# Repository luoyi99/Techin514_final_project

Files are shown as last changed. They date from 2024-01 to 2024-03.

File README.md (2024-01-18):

# Techin514_final_project
## Part 1
### Jumping Jacks Counter
 A basic fitness tracker that monitors and displays key metrics like the number of jumps, rate (jumps per minute), heart rate and calories burned. The project integrates an accelerometer for motion sensing, a pulse sensor for heart rate monitoring, a display mechanism using screen and stepper motor-driven gauge needle, and a button for reset.
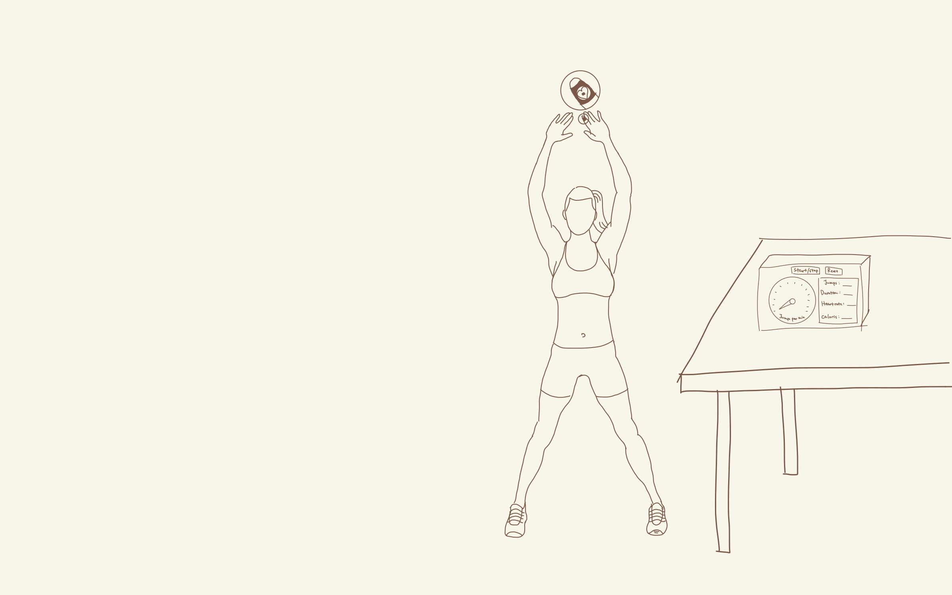
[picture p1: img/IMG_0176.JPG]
Image of how the device work


## Part 2 - Sensor Device
The sensor device will include a MPU6050 motion sensor, a pulse sensor, a ESP32S3 processor and a battery. The components will be sewed on a glove so users can wear it when doing jumping jacks without worrying it to fall down.
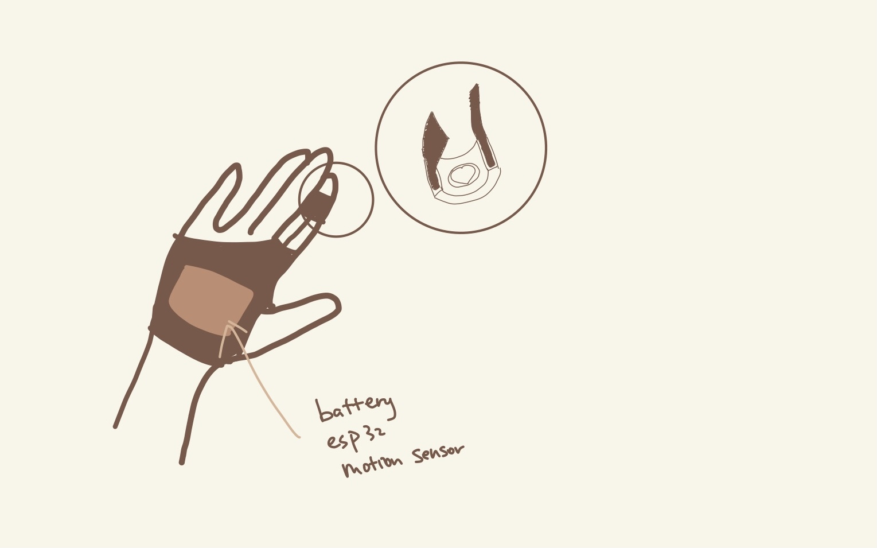
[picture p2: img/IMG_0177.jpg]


## Part 3 - Display Device
The display device will include a ESP32S3 processor, a battery, a OLED screen, a button, a LED, a stepper motor driver breakout board (Adafruit TB6612 1.2A DC/Stepper Motor Driver Breakout Board) and a stepper-motor-driven gauge needle (x27.168). 
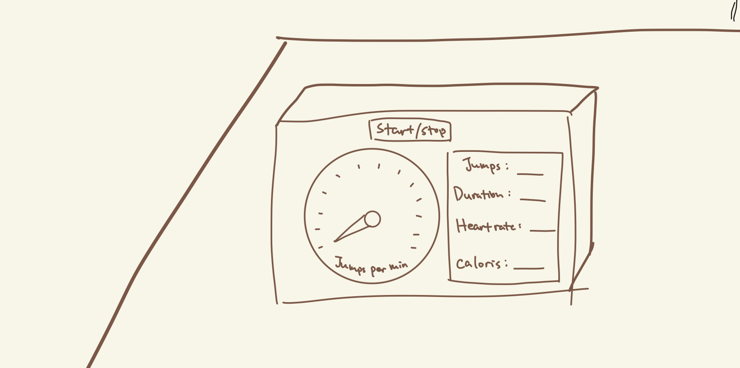
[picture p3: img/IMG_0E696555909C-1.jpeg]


## Part 4
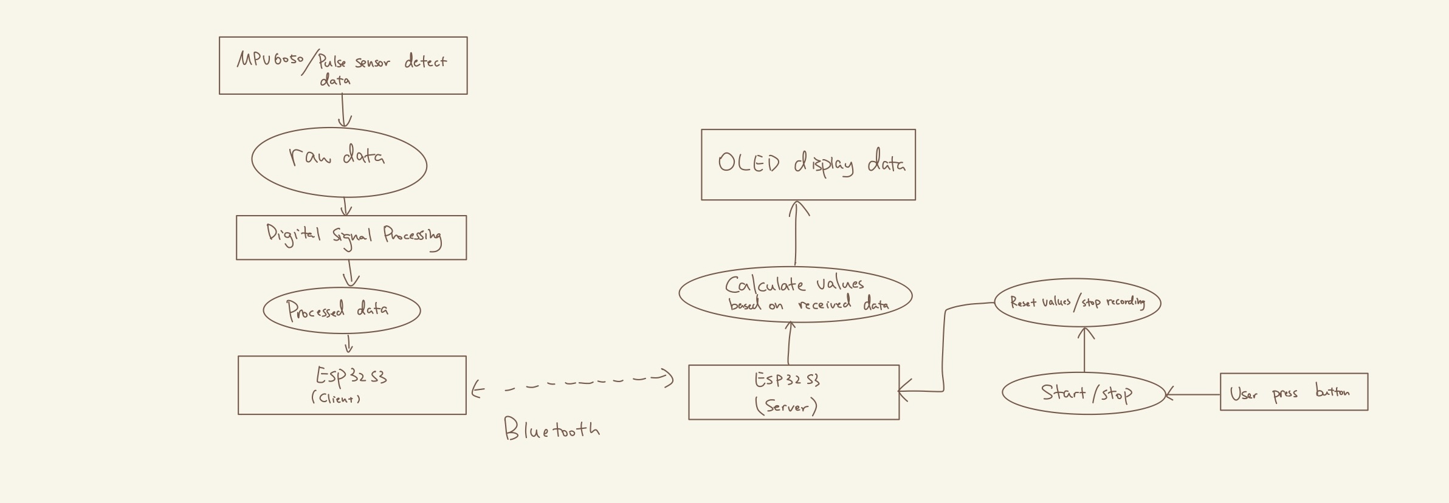
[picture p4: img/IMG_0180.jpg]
Image of how the devices communicate

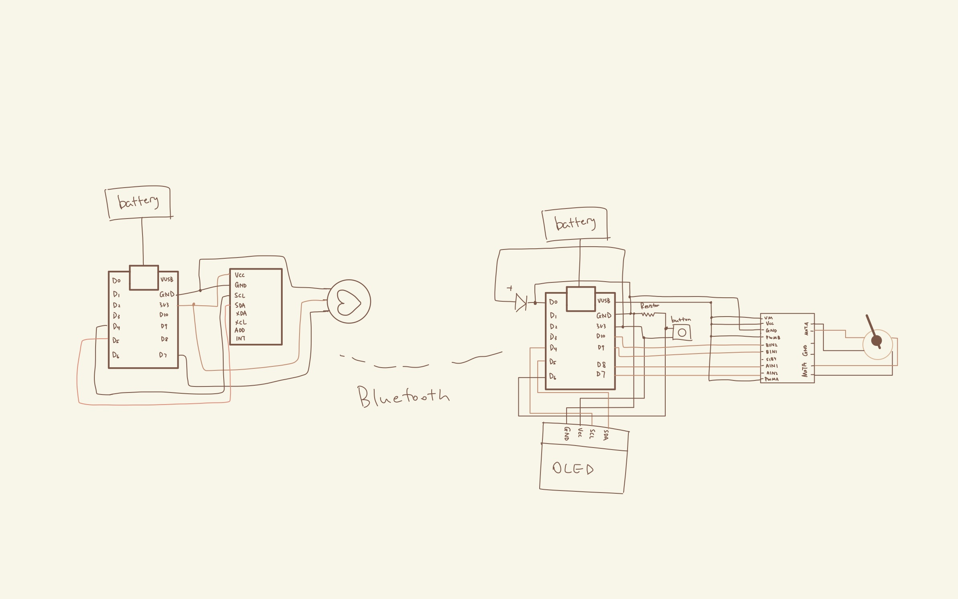
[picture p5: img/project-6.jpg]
Image of how the devices connected


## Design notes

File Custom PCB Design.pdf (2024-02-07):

## Jumping Jacks Counter - Sensor Device

1) A list of all the electronic components that will be soldered to your PCB Resistors
R1 - 1k Ohms
R2 - 4.7k Ohms
R3 - 4.7k Ohms
Capacitors
C4 - 200 pf
C5 - 0.1 uf
C6 - 0.1 uf
C7 - 0.1 uf
Button
Battery holder
LED
Pulse Sensor
SEN - 11574
Motion Sensor
MPU-6050
2) A screenshot of your circuit in the Schematic Editor window of KiCad

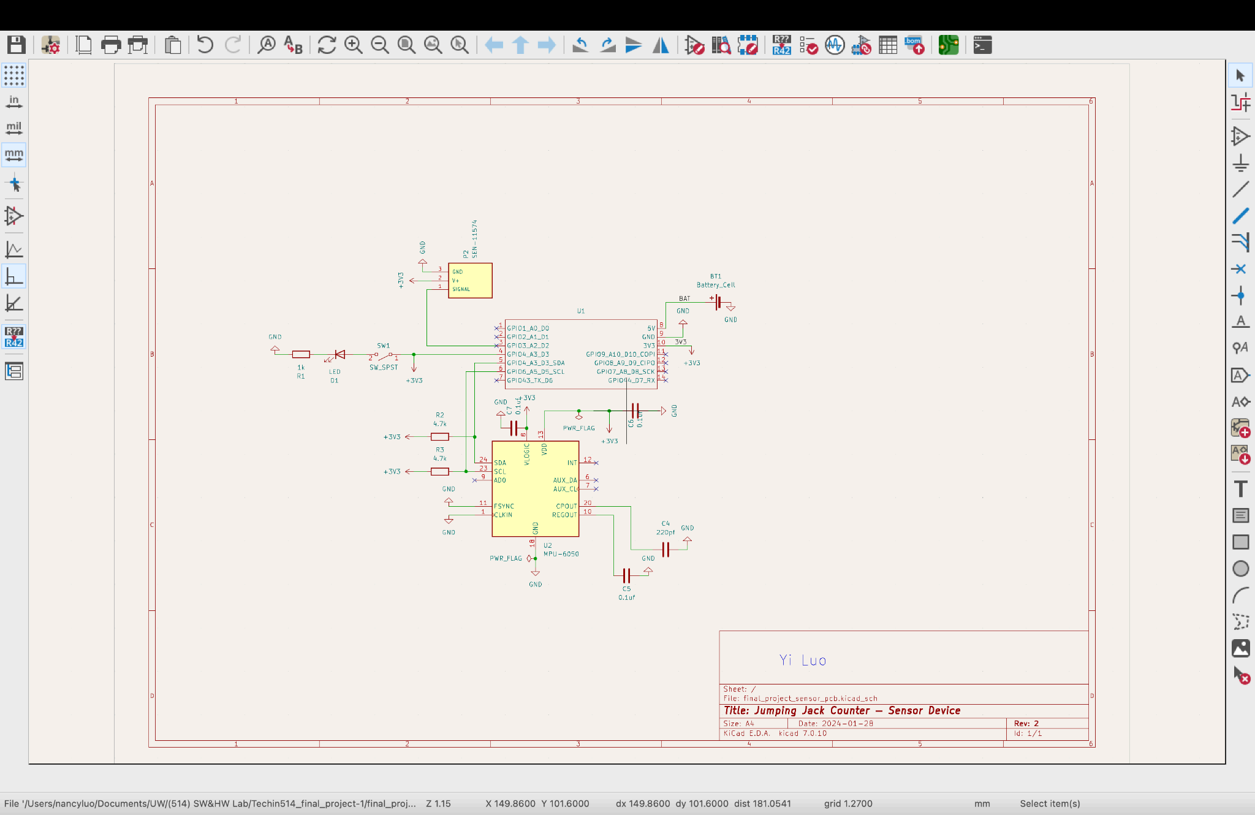
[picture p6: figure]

3) A screenshot of your circuit board in the PCB Editor window of KiCad

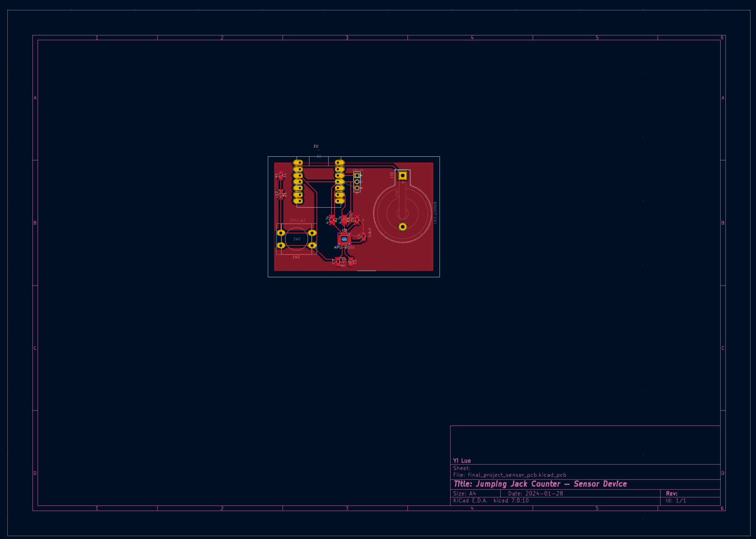
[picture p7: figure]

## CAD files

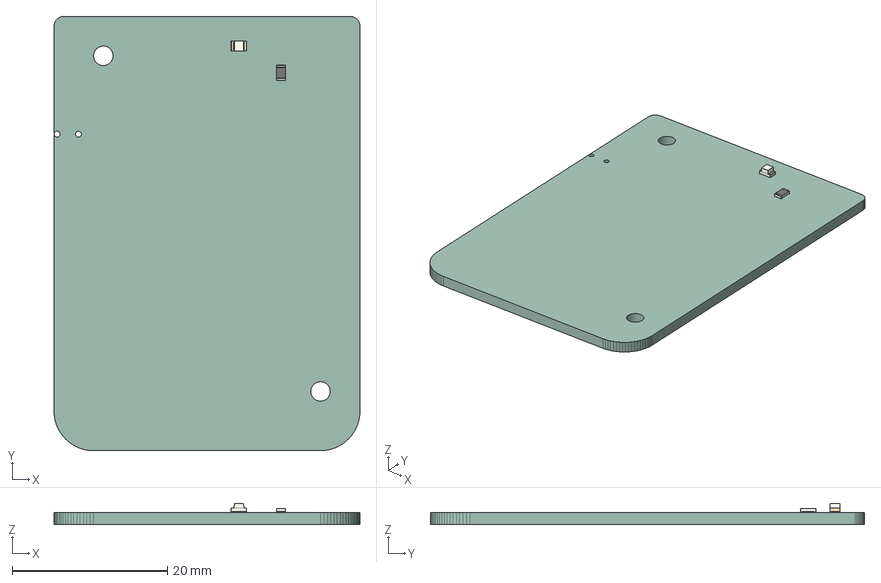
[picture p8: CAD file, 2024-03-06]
CAD/lightboard.step
39.4 x 55.9 x 2.75 mm
lightboard PCB

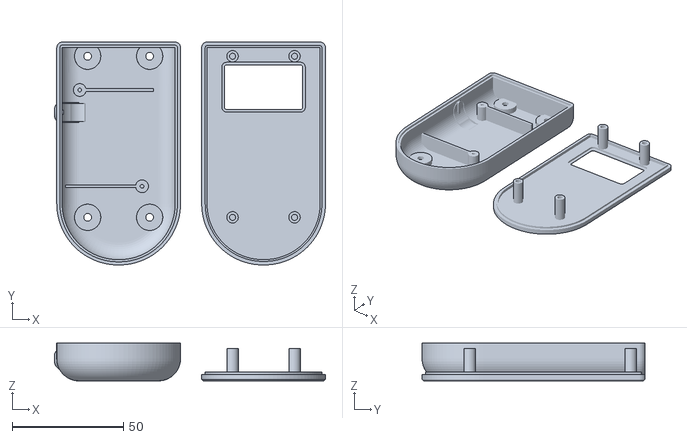
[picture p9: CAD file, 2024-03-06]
CAD/Enclosure_Example_20240207 v1.stl
121.6 x 100.0 x 17.0

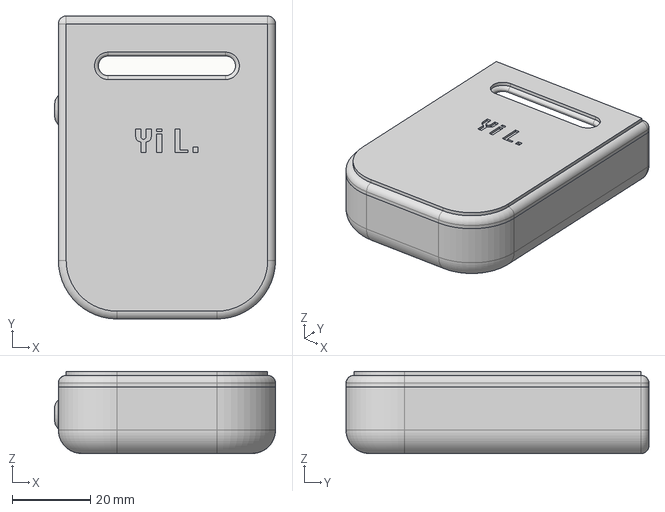
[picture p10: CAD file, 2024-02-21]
PCB/sensor_pcb_breakout_board/EnclosureDesignLabv3 v2.step
56.6 x 77.5 x 21.0 mm

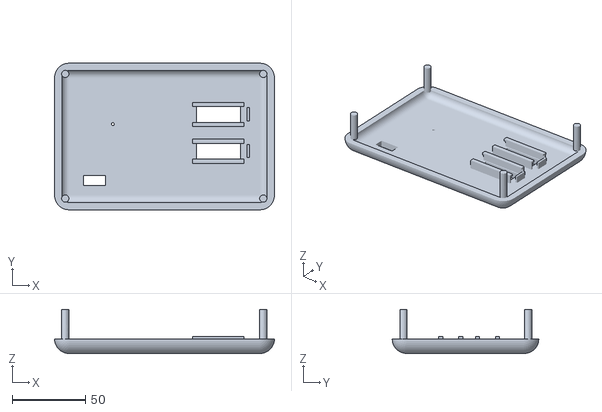
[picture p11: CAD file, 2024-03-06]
CAD/Display v2.stl
150.0 x 100.0 x 30.0

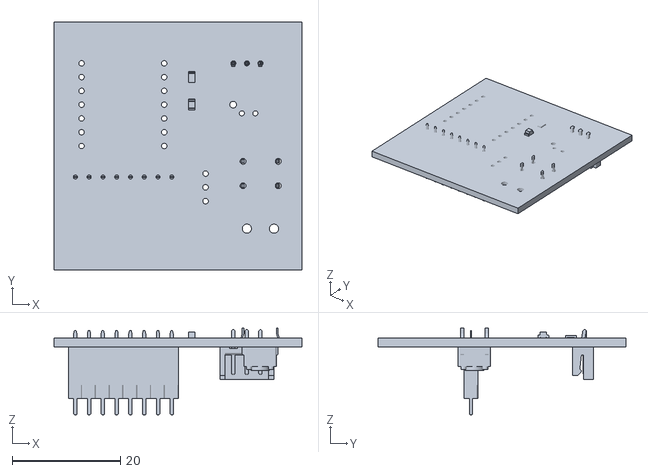
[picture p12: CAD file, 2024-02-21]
PCB/sensor_pcb_breakout_board/final_project_sensor_pcb v1.stl
45.7 x 45.7 x 16.0

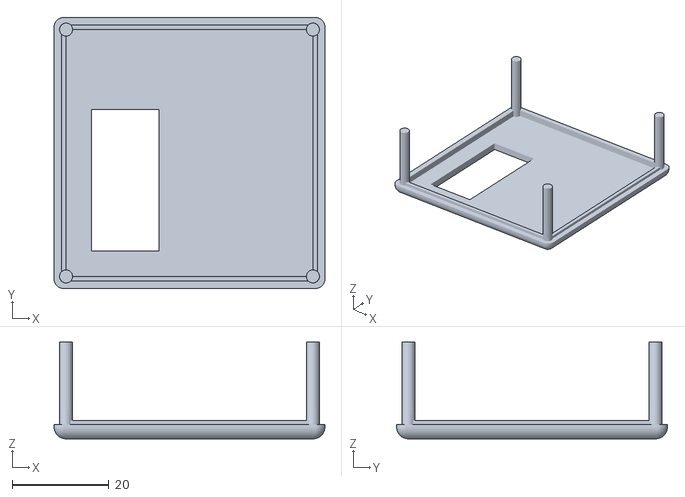
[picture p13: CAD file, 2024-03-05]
CAD/Sensor v3.stl
56.0 x 56.0 x 20.0

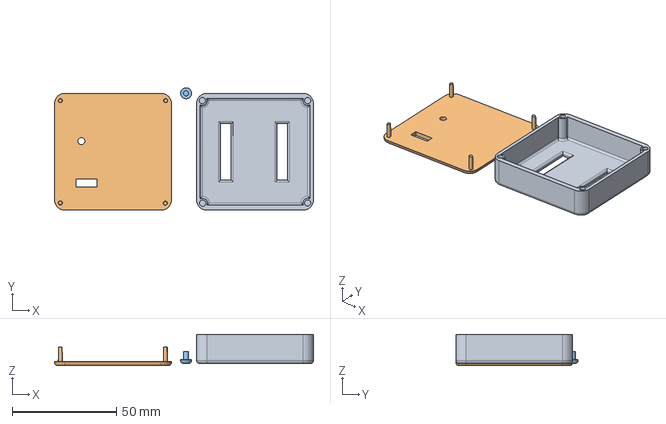
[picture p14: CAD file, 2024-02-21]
PCB/sensor_pcb_breakout_board/Final_Sensor v6.step
124.0 x 58.6 x 15.0 mm

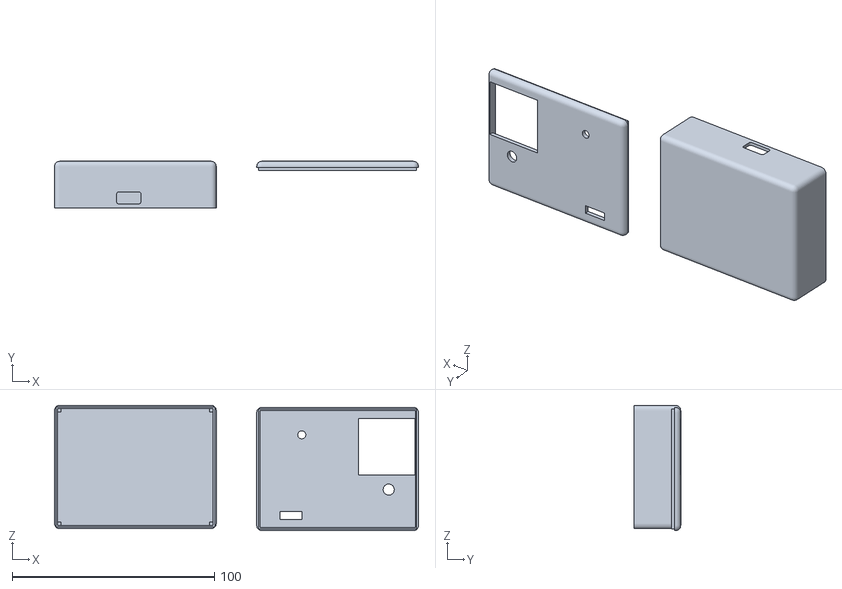
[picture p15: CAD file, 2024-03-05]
CAD/Display_Final v6.stl
180.0 x 23.0 x 62.0

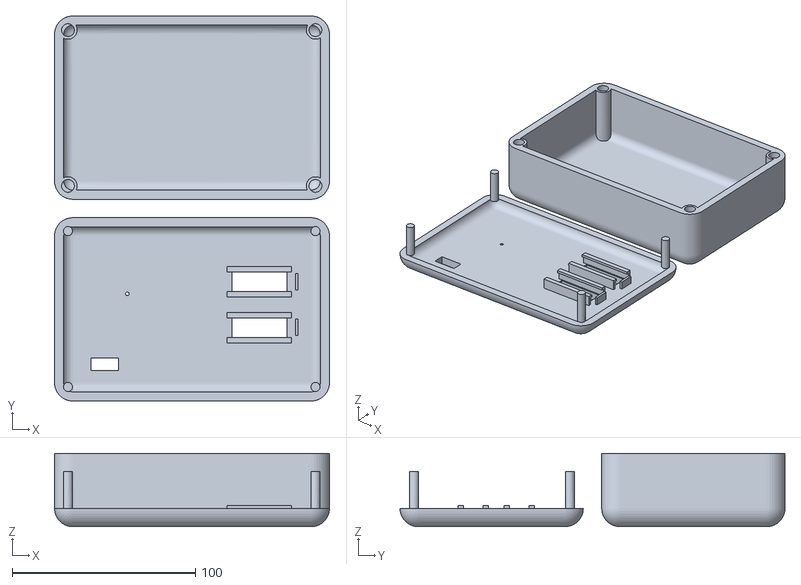
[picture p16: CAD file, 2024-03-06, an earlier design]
CAD/Display v1.stl
150.0 x 210.0 x 40.0

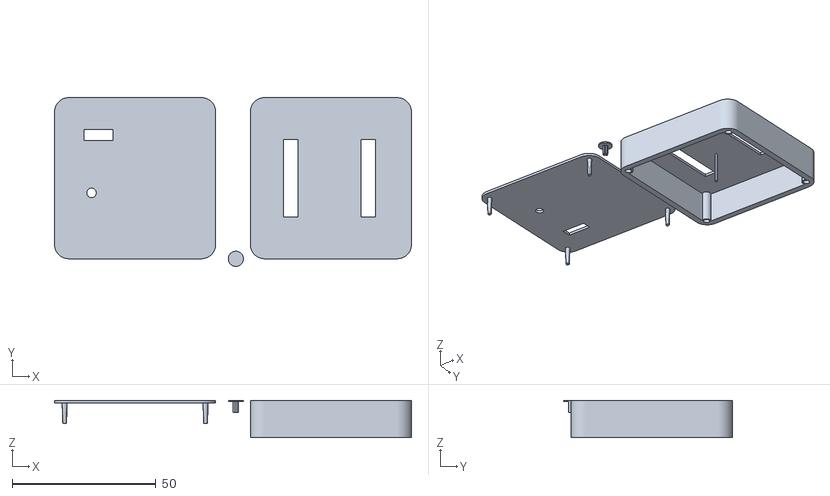
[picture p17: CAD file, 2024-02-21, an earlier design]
PCB/sensor_pcb_breakout_board/Final_Sensor v2.stl
124.0 x 58.6 x 13.0

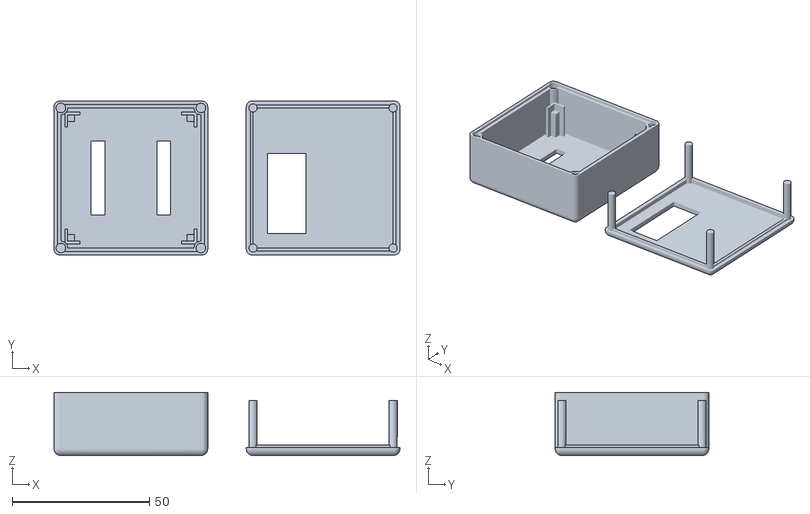
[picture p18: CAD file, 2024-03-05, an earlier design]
CAD/Sensor v2.stl
126.0 x 56.0 x 23.0

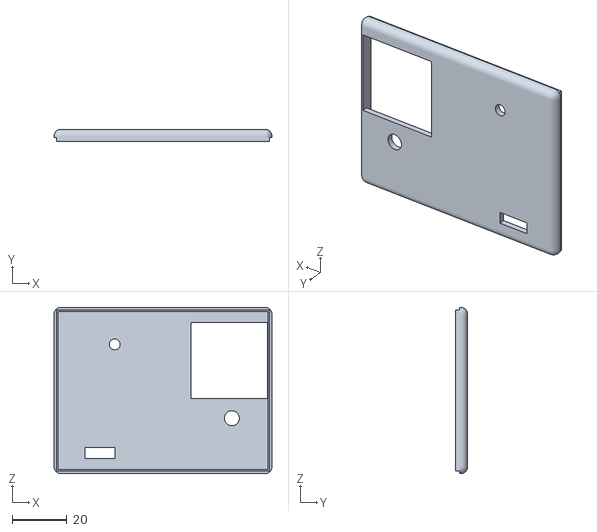
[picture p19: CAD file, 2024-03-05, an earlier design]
CAD/Display_Final v5.stl
80.0 x 4.50 x 61.0

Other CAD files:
PCB/sensor_pcb_breakout_board/final_project_sensor_pcb_2.step
PCB/sensor_pcb_breakout_board/Final_Sensor v3.stl
CAD/Display_Final v3.stl
CAD/Enclosure_Example_20240207 v13.f3d
PCB/sensor_pcb_breakout_board/EnclosureDesignLab v2.f3d
PCB/sensor_pcb_breakout_board/Final_Sensor v6.f3z
PCB/sensor_pcb_breakout_board/Final_Sensor v6.stl

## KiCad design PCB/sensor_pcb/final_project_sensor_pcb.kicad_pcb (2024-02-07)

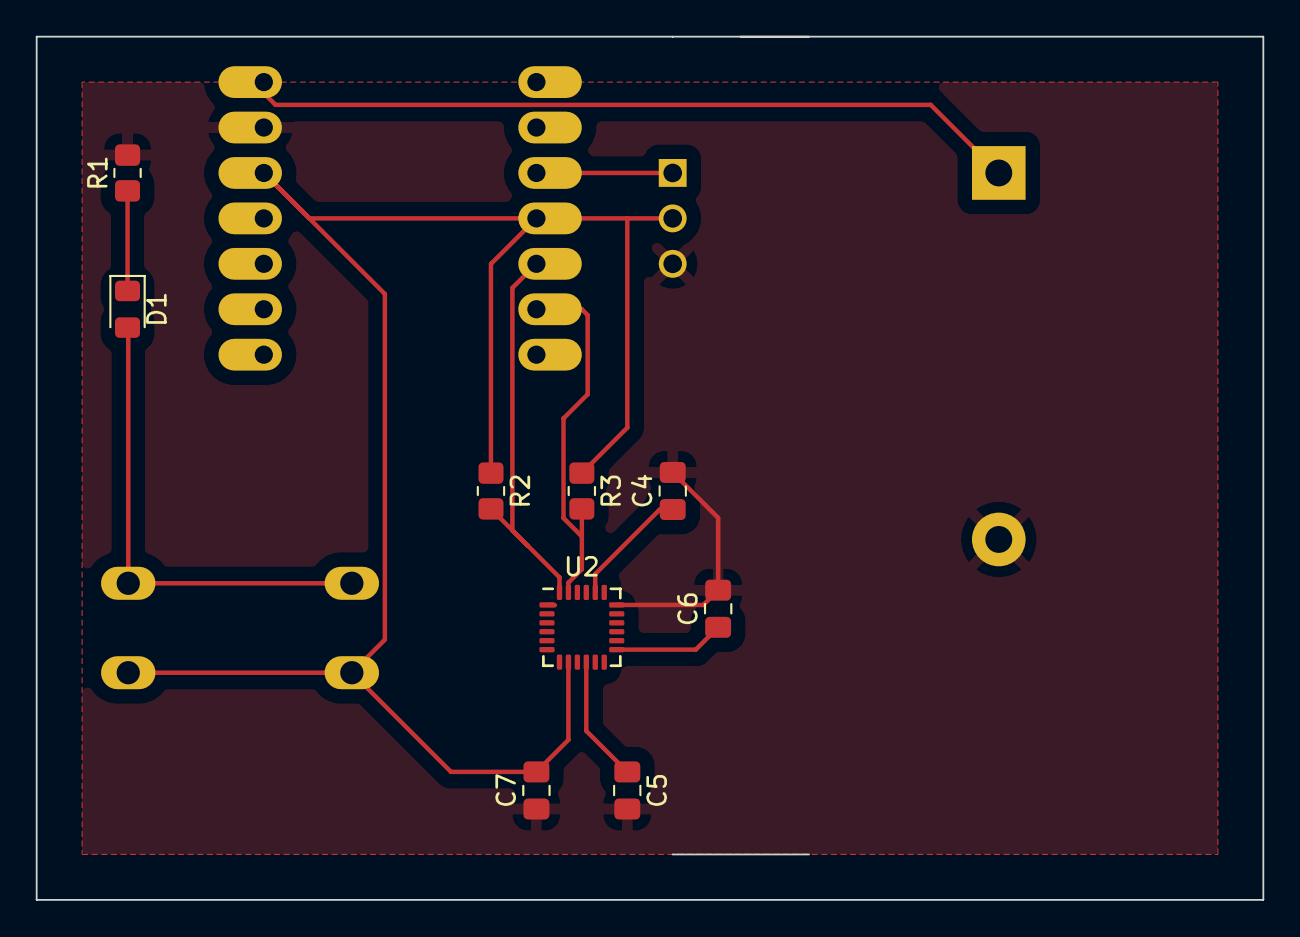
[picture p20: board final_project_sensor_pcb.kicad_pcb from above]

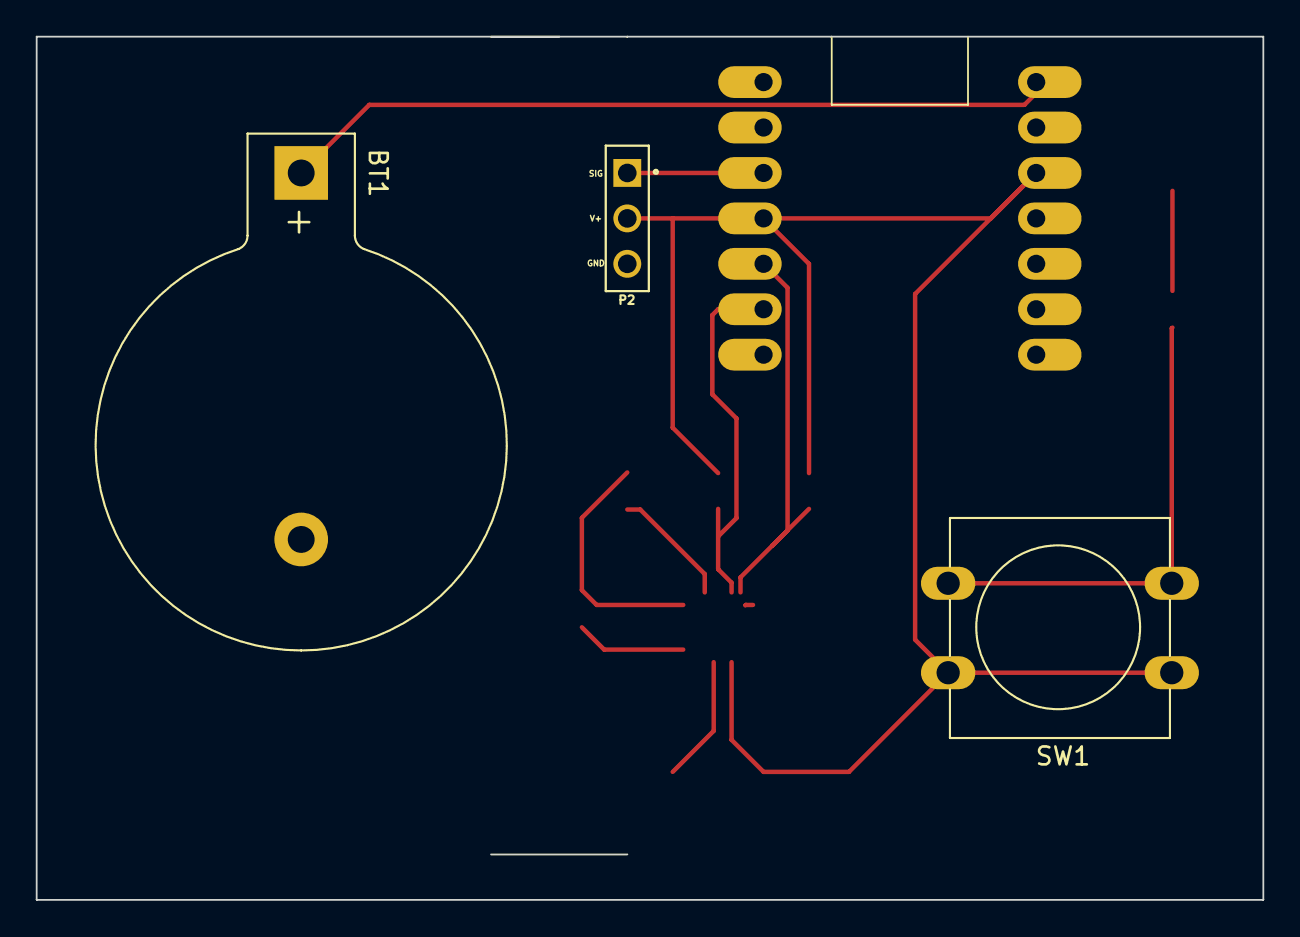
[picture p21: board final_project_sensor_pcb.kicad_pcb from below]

Board: 2 copper layers, 68.6 x 48.3 mm, 13 parts (4 on the bottom side), 9 nets.

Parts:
BT1: Battery_Cell; BatteryHolder_Keystone_103_1x20mm
C4: 220pf; C_0805_2012Metric_Pad1.18x1.45mm_HandSolder
C5, C6, C7: 0.1uf; C_0805_2012Metric_Pad1.18x1.45mm_HandSolder
D1: LED; LED_0805_2012Metric_Pad1.15x1.40mm_HandSolder
P2: SEN-11574; XDCR_SEN-11574
R1: 1k; R_0805_2012Metric_Pad1.20x1.40mm_HandSolder
R2, R3: 4.7k; R_0805_2012Metric_Pad1.20x1.40mm_HandSolder
SW1: SW_SPST; SW_PUSH-12mm
U1: XIAO_ESP32_SENSE
U2: MPU-6050; InvenSense_QFN-24_4x4mm_P0.5mm

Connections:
+3V3: C6.1, C7.2, P2.2 (V+), R2.1, R3.1, SW1.1 (A), U1.4 (GPIO4_A3_D3), U1.10 (3V3), U2.8 (VLOGIC), U2.13 (VDD)
/BAT: BT1.1 (+), U1.8 (5V)
GND: BT1.2 (-), C4.2, C5.2, C6.2, C7.1, P2.3 (GND), R1.2, U1.9 (GND), U2.1 (CLKIN), U2.11 (FSYNC), U2.18 (GND)
unnamed: D1.2 (A), SW1.2 (B)
unnamed: D1.1 (K), R1.1
unnamed: R2.2, U1.5 (GPIO4_A3_D3_SDA), U2.24 (SDA)
unnamed: R3.2, U1.6 (GPIO6_A5_D5_SCL), U2.23 (SCL)
unnamed: C4.1, U2.20 (CPOUT)
unnamed: C5.1, U2.10 (REGOUT)

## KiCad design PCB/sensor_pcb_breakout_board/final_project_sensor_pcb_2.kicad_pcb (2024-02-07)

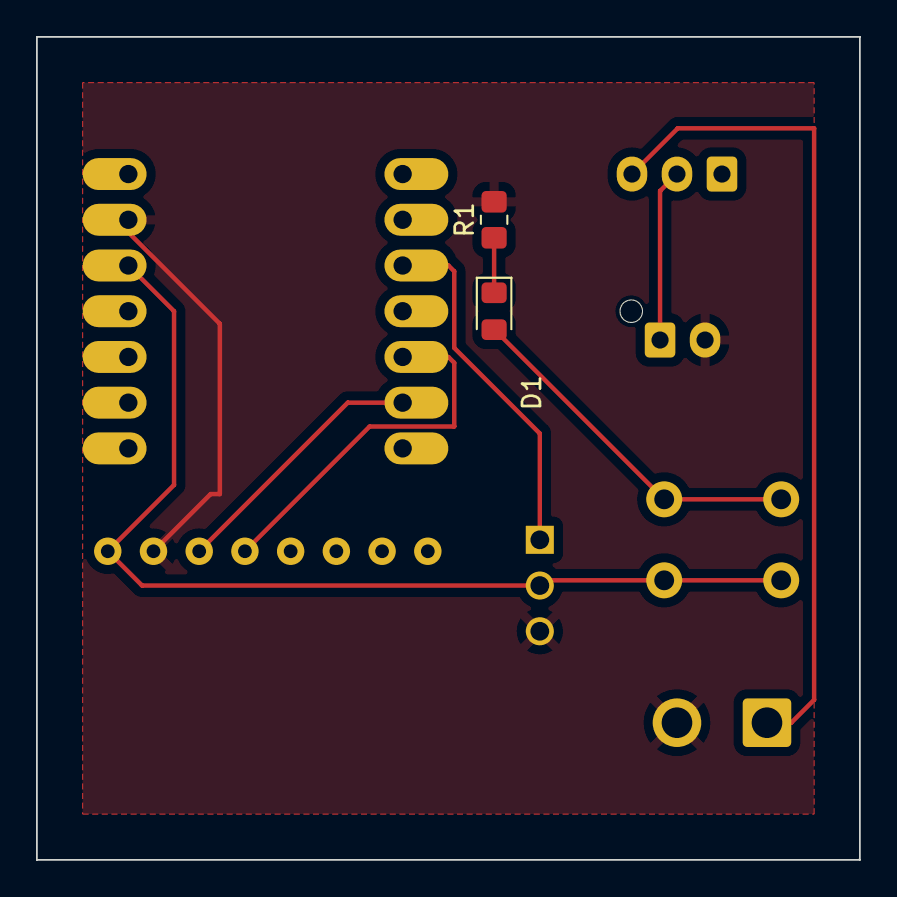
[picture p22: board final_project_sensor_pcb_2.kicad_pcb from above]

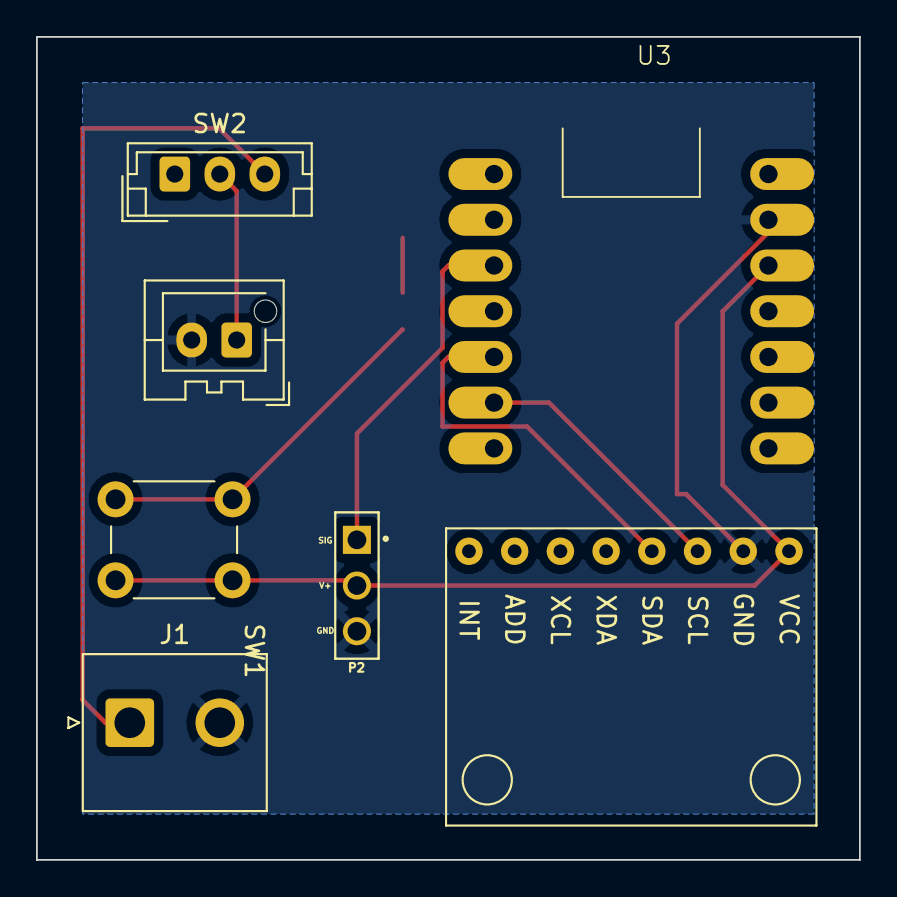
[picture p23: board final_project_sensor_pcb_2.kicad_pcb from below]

Board: 2 copper layers, 45.7 x 45.7 mm, 9 parts (7 on the bottom side), 8 nets.

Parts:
BT1: Battery_Cell; JST_XA_B02B-XASK-1-A_1x02_P2.50mm_Vertical
D1: LED; LED_0805_2012Metric_Pad1.15x1.40mm_HandSolder
J1: Conn_01x02_Pin; JST_NV_B02P-NV_1x02_P5.00mm_Vertical
P2: SEN-11574; XDCR_SEN-11574
R1: 1k; R_0805_2012Metric_Pad1.20x1.40mm_HandSolder
SW1: SW_SPST; SW_PUSH_6mm
SW2: SW_SPDT; JST_EH_B3B-EH-A_1x03_P2.50mm_Vertical
U1: module_mpu6050
U3: XIAO_ESP32_SENSE

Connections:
+3V3: P2.2 (V+), SW1.1 (A), U1.1 (VCC), U3.4 (GPIO4_A3_D3), U3.10 (3V3)
GND: BT1.2 (-), J1.2, P2.3 (GND), R1.2, U1.2 (GND), U3.9 (GND)
unnamed: BT1.1 (+), SW2.2 (B)
unnamed: D1.2 (A), SW1.2 (B)
unnamed: D1.1 (K), R1.1
unnamed: J1.1, SW2.3 (C)
unnamed: U1.3 (SCL), U3.6 (GPIO6_A5_D5_SCL)
unnamed: U1.4 (SDA), U3.5 (GPIO4_A3_D3_SDA)

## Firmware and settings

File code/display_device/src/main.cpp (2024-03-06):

#include <Arduino.h>
#include <BLEDevice.h>
#include <BLEUtils.h>
#include <BLEScan.h>
#include <BLEAdvertisedDevice.h>
// Client Code
#include "BLEDevice.h"
//#include "BLEScan.h"


#include <Wire.h>
#include <Adafruit_GFX.h>
#include <Adafruit_SSD1306.h>

#include <Stepper.h>

#include <iostream>
#include <sstream>
#include <vector>
#include <string>
#include <cstdlib>

struct JumpingJackData {
  int total_jumps;
  unsigned long time;
  bool exerciseSessionStarted;
};


// OLED Screen -----------------------------------------------------------
// -----------------------------------------------------------------------
#define SCREEN_WIDTH 128 // OLED display width, in pixels
#define SCREEN_HEIGHT 64 // OLED display height, in pixels


#define OLED_RESET     -1 // Reset pin # (or -1 if sharing Arduino reset pin)
Adafruit_SSD1306 display1(SCREEN_WIDTH, SCREEN_HEIGHT, &Wire, OLED_RESET);
// -----------------------------------------------------------------------


// Stepper Motor Pin ---------------------------------------------------------
#define stepperPin1 1
#define stepperPin2 2
#define stepperPin3 3
#define stepperPin4 4
const int stepsPerRevolution = 70; 
Stepper myStepper(stepsPerRevolution , stepperPin1, stepperPin2, stepperPin3, stepperPin4);
const int maxRate = 70; // 70 jumps per minute
const int minRate = 0; // 0 jumps per minute
static int lastPosition = 0;

// LED Pin-----------------------------------------------------------------------  
const int ledPin = D9; // the number of the LED pin

// BLE Client ------------------------------------------------------------
// -----------------------------------------------------------------------
// The remote service we wish to connect to.
static BLEUUID serviceUUID("014805bf-7587-47e5-8965-b11fef29d012");
// The characteristic of the remote service we are interested in.
static BLEUUID    charUUID("47b36193-f67b-4a77-ad27-0cafb5dd7a91");

static boolean doConnect = false;
static boolean connected = false;
static boolean doScan = false;
static BLERemoteCharacteristic* pRemoteCharacteristic;
static BLEAdvertisedDevice* myDevice;


static void notifyCallback(
  BLERemoteCharacteristic* pBLERemoteCharacteristic,
  uint8_t* pData,
  size_t length,
  bool isNotify) {
\
    JumpingJackData receivedSensorData;
    memcpy(&receivedSensorData, pData, sizeof(JumpingJackData));

    int totalJumps = receivedSensorData.total_jumps;
    float elapsedTime = receivedSensorData.time / 60000.0; // 60000 milliseconds in a minute
    bool exerciseSessionStarted = receivedSensorData.exerciseSessionStarted;

    if (receivedSensorData.exerciseSessionStarted == 1) {
      digitalWrite(ledPin, HIGH);
    
      int jumpingRate = static_cast<int>(totalJumps / elapsedTime);
      Serial.print("total jumps: ");
      Serial.println(totalJumps);
      Serial.print("time: ");
      Serial.println(elapsedTime);
      Serial.print("jumping rate: ");
      Serial.println(jumpingRate);
      Serial.print("exerciseSessionStarted: ");
      Serial.println(receivedSensorData.exerciseSessionStarted);

      
      display1.clearDisplay();
      display1.setTextSize(1);
      display1.setTextColor(SSD1306_WHITE);
      display1.setCursor(0,0);
      display1.println("Total Jumps:");
      display1.println();
      display1.setTextSize(4);
      display1.println(totalJumps);
      display1.display();

      int stepsToMove = map(jumpingRate, minRate, maxRate, 0, stepsPerRevolution);
      Serial.print("last position: ");
      Serial.println(lastPosition);
      Serial.print("steps to move: ");
      Serial.println(stepsToMove);
      int moveSteps = stepsToMove - lastPosition;
      Serial.print("move steps: ");
      Serial.println(moveSteps);
      Serial.println(-500/70*moveSteps);
      myStepper.step(-500/70*moveSteps);
      delay(300);
      lastPosition = stepsToMove;
    } else {
      digitalWrite(ledPin, LOW);
      display1.clearDisplay();
      display1.setTextSize(2);
      display1.setTextColor(SSD1306_WHITE);
      display1.setCursor(0,0);
      display1.println("Exercise");
      display1.println("Stopped");
      display1.display();
    }

    

}

class MyClientCallback : public BLEClientCallbacks {
  void onConnect(BLEClient* pclient) {
  }

  void onDisconnect(BLEClient* pclient) {
    connected = false;
    Serial.println("onDisconnect");
  }
};

bool connectToServer() {
    Serial.print("Forming a connection to ");
    Serial.println(myDevice->getAddress().toString().c_str());

    BLEClient*  pClient  = BLEDevice::createClient();
    Serial.println(" - Created client");

    pClient->setClientCallbacks(new MyClientCallback());

    // Connect to the remove BLE Server.
    pClient->connect(myDevice);  // if you pass BLEAdvertisedDevice instead of address, it will be recognized type of peer device address (public or private)
    Serial.println(" - Connected to server");
    pClient->setMTU(517); //set client to request maximum MTU from server (default is 23 otherwise)

    // Obtain a reference to the service we are after in the remote BLE server.
    BLERemoteService* pRemoteService = pClient->getService(serviceUUID);
    if (pRemoteService == nullptr) {
      Serial.print("Failed to find our service UUID: ");
      Serial.println(serviceUUID.toString().c_str());
      pClient->disconnect();
      return false;
    }
    Serial.println(" - Found our service");

    // Obtain a reference to the characteristic in the service of the remote BLE server.
    pRemoteCharacteristic = pRemoteService->getCharacteristic(charUUID);
    if (pRemoteCharacteristic == nullptr) {
      Serial.print("Failed to find our characteristic UUID: ");
      Serial.println(charUUID.toString().c_str());
      pClient->disconnect();
      return false;
    }
    Serial.println(" - Found our characteristic");

    // Read the value of the characteristic.
    if(pRemoteCharacteristic->canRead()) {
      std::string value = pRemoteCharacteristic->readValue();
      Serial.print("The characteristic value was: ");
      Serial.println(value.c_str());
    }

    if(pRemoteCharacteristic->canNotify())
      pRemoteCharacteristic->registerForNotify(notifyCallback);

    connected = true;
    return true;
}
/**
 * Scan for BLE servers and find the first one that advertises the service we are looking for.
 */
class MyAdvertisedDeviceCallbacks: public BLEAdvertisedDeviceCallbacks {
  /**
   * Called for each advertising BLE server.
   */
  void onResult(BLEAdvertisedDevice advertisedDevice) {
    Serial.print("BLE Advertised Device found: ");
    Serial.println(advertisedDevice.toString().c_str());

    // We have found a device, let us now see if it contains the service we are looking for.
    if (advertisedDevice.haveServiceUUID() && advertisedDevice.isAdvertisingService(serviceUUID)) {

      BLEDevice::getScan()->stop();
      myDevice = new BLEAdvertisedDevice(advertisedDevice);
      doConnect = true;
      doScan = true;

    } // Found our server
  } // onResult
}; // MyAdvertisedDeviceCallbacks

// -----------------------------------------------------------------------


// Setup function   ------------------------------------------------------
// -----------------------------------------------------------------------
void setup() {
    Serial.begin(115200);
    Wire.begin();

    Serial.println("Starting Arduino BLE Client application...");
    BLEDevice::init("");

    // Retrieve a Scanner and set the callback we want to use to be informed when we
    // have detected a new device.  Specify that we want active scanning and start the
    // scan to run for 15 seconds.
    BLEScan* pBLEScan = BLEDevice::getScan();
    pBLEScan->setAdvertisedDeviceCallbacks(new MyAdvertisedDeviceCallbacks());
    pBLEScan->setInterval(1349);
    pBLEScan->setWindow(449);
    pBLEScan->setActiveScan(true);
    pBLEScan->start(15, false);

    // OLED Screen setup
    if(!display1.begin(SSD1306_SWITCHCAPVCC, 0x3C)) { 
        Serial.println(F("SSD1306 allocation failed for display 1"));
        for(;;); // Don't proceed, loop forever
    }
    display1.clearDisplay();
    display1.setTextSize(1);
    display1.setTextColor(SSD1306_WHITE);
    display1.setCursor(0,0);
    display1.println(F("Initializing Screen"));
    display1.display();
    Serial.println("Screen 1 initialized");

    pinMode(ledPin, OUTPUT);


    // Stepper Motor setup
    myStepper.setSpeed(400);

} // End of setup.

// -----------------------------------------------------------------------


// Loop function   -------------------------------------------------------
// -----------------------------------------------------------------------
// This is the Arduino main loop function.
void loop() {

  if (doConnect == true) {
    if (connectToServer()) {
      Serial.println("We are now connected to the BLE Server.");
    } else {
      Serial.println("We have failed to connect to the server; there is nothin more we will do.");
    }
    doConnect = false;
  }
 
  // If we are connected to a peer BLE Server, update the characteristic each time we are reached
  // with the current time since boot.
  if (connected) {

    String newValue = "Time since boot: " + String(millis()/1000);
    Serial.println("Setting new characteristic value to \"" + newValue  + "\"");

    // Set the characteristic's value to be the array of bytes that is actually a string.
    pRemoteCharacteristic->writeValue(newValue.c_str(), newValue.length());
  }else if(doScan){
    BLEDevice::getScan()->start(0);  // this is just example to start scan after disconnect, most likely there is better way to do it in arduino
  }

  delay(500); // Delay a second between loops.
} 

// End of loop
// -----------------------------------------------------------------------

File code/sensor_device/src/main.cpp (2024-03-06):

#include <Adafruit_MPU6050.h>
#include <Wire.h>

// Bluetooth
#include <Arduino.h>
#include <BLEDevice.h>
#include <BLEServer.h>
#include <BLEUtils.h>
#include <BLE2902.h>
#include <stdlib.h>

#include <iostream> 


//  Variables
const int PushButtonPin = D8; // Push button connected to digital pin 8
bool exerciseSessionStarted = true;

// Jumping jacks data
bool isJumping = false;
float lastAccZ = 0;
int total_jumps = 0;
int valid_jumps = 0;
String message = "";

// MPU6050 sensor
Adafruit_MPU6050 mpu;


// BLE
BLEServer* pServer = NULL;
BLECharacteristic* pCharacteristic = NULL;
bool deviceConnected = false;
bool oldDeviceConnected = false;
unsigned long previousMillis = 0;
const long interval = 500;

// Time interval
unsigned long startTime;
unsigned long currentTime;

struct JumpingJackData {
  int total_jumps;
  unsigned long time;
  bool exerciseSessionStarted;
};




#define SERVICE_UUID        "014805bf-7587-47e5-8965-b11fef29d012"
#define CHARACTERISTIC_UUID "47b36193-f67b-4a77-ad27-0cafb5dd7a91"

class MyServerCallbacks : public BLEServerCallbacks {
    void onConnect(BLEServer* pServer) {
        deviceConnected = true;
    };

    void onDisconnect(BLEServer* pServer) {
        deviceConnected = false;
    }
};

// Function to count the number of jumping jacks
void processSensorData(sensors_event_t a, float threshold) {
    // If there's a significant positive change in acceleration, we might be starting a jump
    float accX = a.acceleration.x;
    float accY = a.acceleration.y;
    float accZ = a.acceleration.z;
    Serial.print(lastAccZ);
    Serial.print(" ");
    Serial.println(accZ);

    if (accZ - lastAccZ > threshold && !isJumping) {
        isJumping = true;
    }
    // If we're in a jump and there's a significant negative change, the jump is ending
    else if (isJumping && lastAccZ - accZ > threshold) {
        isJumping = false; // Reset jump state
        total_jumps++;       // Increment the jump count
        std::cout << "Jumping Jacks Count: " << total_jumps << std::endl;
    }

    // Update the last acceleration value for the next call
    lastAccZ = accZ;

}




void setup() {   

  Serial.begin(115200);          // For Serial Monitor
  

  pinMode(PushButtonPin, INPUT_PULLUP);  // Initialize the push button pin as an input with internal pull-up resistor


  // MPU6050 sensor
  // while (!Serial)
  //   delay(10); // will pause Zero, Leonardo, etc until serial console opens

  Serial.println("Adafruit MPU6050 test!");

  if (!mpu.begin()) {
    Serial.println("Failed to find MPU6050 chip");
    while (1) {
      delay(10);
    }
  }
  Serial.println("MPU6050 Found!");

  mpu.setAccelerometerRange(MPU6050_RANGE_8_G);
  Serial.print("Accelerometer range set to: ");
  switch (mpu.getAccelerometerRange()) {
  case MPU6050_RANGE_2_G:
    Serial.println("+-2G");
    break;
  case MPU6050_RANGE_4_G:
    Serial.println("+-4G");
    break;
  case MPU6050_RANGE_8_G:
    Serial.println("+-8G");
    break;
  case MPU6050_RANGE_16_G:
    Serial.println("+-16G");
    break;
  }

  mpu.setGyroRange(MPU6050_RANGE_500_DEG);
  Serial.print("Gyro range set to: ");
  switch (mpu.getGyroRange()) {
  case MPU6050_RANGE_250_DEG:
    Serial.println("+- 250 deg/s");
    break;
  case MPU6050_RANGE_500_DEG:
    Serial.println("+- 500 deg/s");
    break;
  case MPU6050_RANGE_1000_DEG:
    Serial.println("+- 1000 deg/s");
    break;
  case MPU6050_RANGE_2000_DEG:
    Serial.println("+- 2000 deg/s");
    break;
  }

  mpu.setFilterBandwidth(MPU6050_BAND_21_HZ);
  Serial.print("Filter bandwidth set to: ");
  switch (mpu.getFilterBandwidth()) {
  case MPU6050_BAND_260_HZ:
    Serial.println("260 Hz");
    break;
  case MPU6050_BAND_184_HZ:
    Serial.println("184 Hz");
    break;
  case MPU6050_BAND_94_HZ:
    Serial.println("94 Hz");
    break;
  case MPU6050_BAND_44_HZ:
    Serial.println("44 Hz");
    break;
  case MPU6050_BAND_21_HZ:
    Serial.println("21 Hz");
    break;
  case MPU6050_BAND_10_HZ:
    Serial.println("10 Hz");
    break;
  case MPU6050_BAND_5_HZ:
    Serial.println("5 Hz");
    break;
  }


  // BLE
  Serial.println("Starting BLE work!");

  // TODO: name your device to avoid conflictions
  BLEDevice::init("Yi_L_XIAO_ESP32S3");
  pServer = BLEDevice::createServer();
  pServer->setCallbacks(new MyServerCallbacks());
  BLEService *pService = pServer->createService(SERVICE_UUID);
  pCharacteristic = pService->createCharacteristic(
      CHARACTERISTIC_UUID,
      BLECharacteristic::PROPERTY_READ |
      BLECharacteristic::PROPERTY_WRITE |
      BLECharacteristic::PROPERTY_NOTIFY
  );
  pCharacteristic->addDescriptor(new BLE2902());
  pCharacteristic->setValue("Connected");
  pService->start();
  // BLEAdvertising *pAdvertising = pServer->getAdvertising();  // this still is working for backward compatibility
  BLEAdvertising *pAdvertising = BLEDevice::getAdvertising();
  pAdvertising->addServiceUUID(SERVICE_UUID);
  pAdvertising->setScanResponse(true);
  pAdvertising->setMinPreferred(0x06);  // functions that help with iPhone connections issue
  pAdvertising->setMinPreferred(0x12);
  BLEDevice::startAdvertising();
  Serial.println("Characteristic defined! Now you can read it in your phone!");

  startTime = millis();



}
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
